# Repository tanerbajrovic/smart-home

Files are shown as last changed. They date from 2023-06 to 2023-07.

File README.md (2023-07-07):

# Smart Home

## About

An intruder alarm system realised on Raspberry Pi Pico. Our system currently supports following functionalities:

- Passcode setup
- User-friendly GUI
- Alarm activation and deactivation
  - Deactivation over MQTT protocol
- Movement detection and siren activation
- Protection against too many unlock attempts

## Components

In the project we used the following components:
- 1x Raspberry Pi Pico*
- 1x Matrix Keypad
- 1x PIR Sensor
- 1x LCD TFT Banggood Display
- 1x Buzzer

For the implementation details, documentation, or schemes please refer to the `docs` directory. 

Please also note that we actually used a modified version of Raspberry Pi Pico called PicoETF, developed at ETF Sarajevo. The differences are minute but important to state because of possible differences in schematics.

## Team Members

Below you can see all the team members who worked on this project.
- [Taner Bajrovic](mailto:tbajrovic1@etf.unsa.ba)
- [Edwin Graza](mailto:egraza1@etf.unsa.ba)
- [Ajna Mujkić](mailto:amujkic1@etf.unsa.ba)

## Notice
This project was done as part of coursework for **Embedded Systems 22/23** at the Faculty of Electrical Engineering Sarajevo.

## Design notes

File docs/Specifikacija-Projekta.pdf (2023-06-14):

### Specifikacija projekta iz

### Ugradbenih Sistema

# Smart Home

### Taner Bajrovic´, Edwin Graca, Ajna Mujkic´

## 1 Uvod

Osnovna ideja sistema pametne kuće je integracija grijanja, hladenja, rasvjete, te alarma protiv provale i požara. U osnovi cijelog sistema je jedan procesorski sistem koji kontroliše i upravlja svim ostalim kućnim sistemima. Centralni procesor dobija te informacije iz vanjskog svijeta putem raznih senzora.

U našem projektu, mi ćemo se fokusirati na implementaciju alarmnog sistema pametne kuće. U pitanju je sistem koji će omogućiti da se odredeni prostor pokrije senzorima za detekciju pokreta, aktivira/deaktivira alarm, te u odredenim situacijama aktivira sirena. Osim toga, sistem će omogućiti da se pošalje signal korisniku ukoliko se neko nalazi ispred vrata.

## 2 Implementacija

U ovom dijelu ćemo predložiti listu hardverskih komponenti, kao i predstaviti funkcionalnosti sistema.

### 2.1 Hardverske komponente

Za izradu zamišljenog sistema, potrebne su sljedeće komponente:

- 1x Raspberry Pi Pico (PicoETF)
- 1x Matrična tastatura
- 2x Magnetni senzor
- 3x PIR senzor
- 1x Fotootpornik
- 1x LCD displej (Banggood TFT)
- 1x Buzzer/Beeper (alt. LED dioda)

Povezanost izmedu pomenutih komponenti sistema i potencijalni raspored možete vidjeti na Slici 1.

1

Ugradbeni sistemi 2022./2023. | Specifikacija projekta

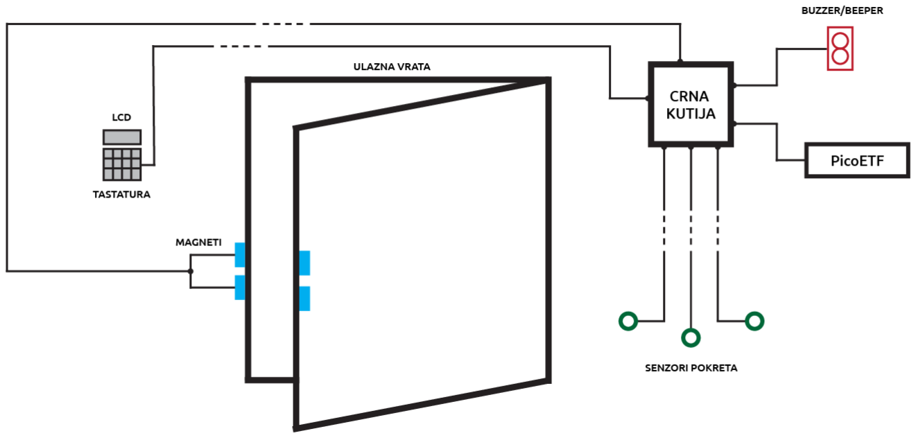
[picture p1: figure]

Slika 1: Prikaz pozicija i povezanosti komponenti

### 2.2 Funkcionalnosti sistema

Zamišljeni sistem ima sljedeće funkcionalnosti:

- Aktivacija/deaktivacija alarma. Korisnik će moći da izvrši aktivaciju i deaktivaciju alarma pomoću LCD displeja i matrične tastature. Ulaskom u odredeni režim rada i potom unosom šifre, korisnik će moći aktivirati alarm. Deaktivacija alarma će se obavljati unosom ispravne šifre nakon što je alarm već aktiviran.
- Odredeni period za unos šifre. Nakon što otvori vrata, korisnik će morati ukucati šifru u odredenom vremenskom periodu. Ukoliko to ne uradi, sistem će aktivirati zvučni signal pomoću sirene.
- Paljenje sirene u slučaju pogrešne šifre ili aktivacije senzora pokreta. U slučaju da korisnik prilikom deaktivacije alarma unese neispravnu šifru, sistem će aktivirati zvučni signal pomoću sirene/buzzer-a. Ista sirena će biti aktivirana ukoliko neki od PIR senzora detektuje neko kretanje.
- Deaktivacija sirene i alarma. Nakon što je aktivirana sirena, korisnik će moći deaktivirati alarm i sirenu unosom ispravne šifre.
- Obavještavanje o posjeti. U slučaju da se neka osoba nalazi ispred vrata, sistem će to moći detektovati i tu informaciju prenijeti korisniku.

2

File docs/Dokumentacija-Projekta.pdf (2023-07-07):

Dokumentacija Projekta iz

Ugradbenih Sistema

# Smart Home

### Taner Bajrovic´, Edwin Graca, Ajna Mujkic´

## Sadržaj

1 Uvod | 1
2 Dijagram stanja | 1
3 Kod | 1
3.1
3.2
3.3
3.4
3.5
Korištene oznake CLS | Klasa Oznaka za klasu MDL | Modul Oznaka za modul

host/tema Oznaka za temu

Stanje Oznaka za stanje

Ugradbeni sistemi 2022./2023. | Dokumentacija projekta

## 1 Uvod

Kao projekat na predmetu ‘Ugradbeni Sistemi’ implementirali smo alarm koji se može integrirati u neki Smart house sistem. Sklop omogućava da se odredeni prostor pokrije senzorima za detekciju pokreta, aktivira/deaktivira alarm te unese lozinka za njegovo isključivanje. Unos lozinke se izvršava putem displeja i tastature. Ako je detektovano kretanje u zaštićenoj zoni, vlasniku se šalje poruka na mobitel putem MQTT protokola, a on može i isključiti alarm putem aplikacije koja podržava MQTT.

## 2 Dijagram stanja

Prvobitno je alarm u stanju Deactivated . Ako se osoba pojavi u zaštićenoj zoni aktivira se alarm i sistem prelazi u stanje Activated i u njemu ostaje sve dok korisnik ima preostalih pokušaja za unos lozinke. Ukoliko se netačna lozinka unese 3 puta sistem ulazi u stanje Bricked i u njemu ostaje dok ima napajanja.

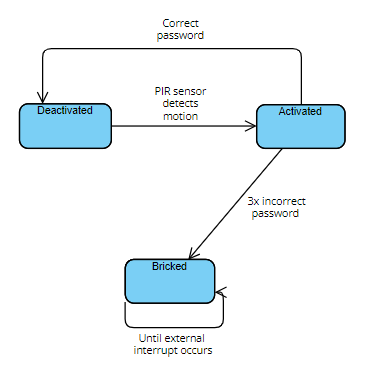
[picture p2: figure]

Slika 1. State diagram

## 3 Kod

3.1

### CLSAlarmState

Klasa

CLSAlarmState , koja se nalazi unutar modula

MDL Alarm , sadrži metode za prijelaze izmedu različitih stanja u kojima se sistem može nalaziti. U nastavku ćemo ukratko proći kroz metode ove klase te objasniti ulogu svake:

hasCode(self)-> bool

Provjerava da li je postavljena lozinka.

isLocked(self)-> bool

Provjerava da li je alarm uključen.

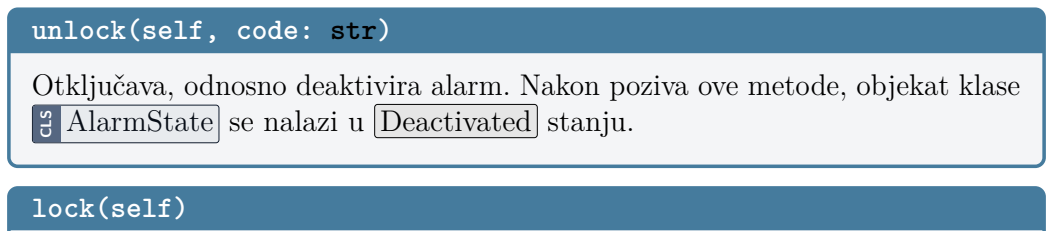
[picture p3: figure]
unlock(self, code: str); lock(self)

Otključava, odnosno deaktivira alarm. Nakon poziva ove metode, objekat klase CLS | AlarmState se nalazi u Deactivated stanju.

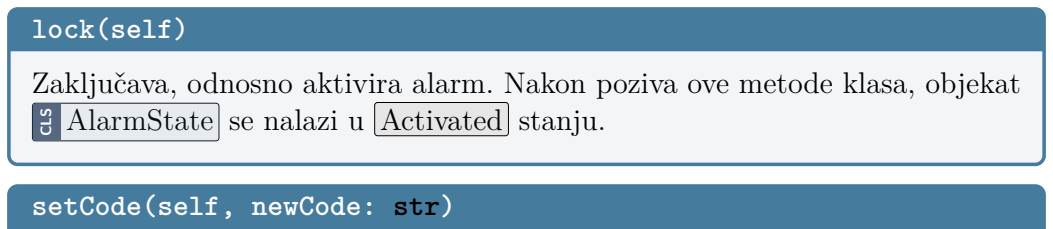
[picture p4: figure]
setCode(self, newCode: str)

Zaključava, odnosno aktivira alarm. Nakon poziva ove metode klasa, objekat CLS | AlarmState se nalazi u Activated stanju.

Postavlja novu lozinku koja je proslijedena kao argument newCode.

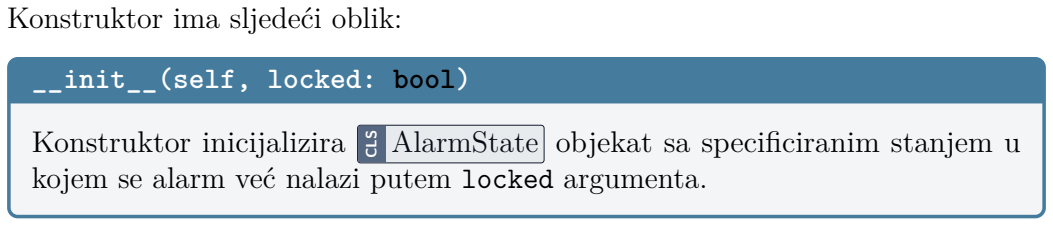
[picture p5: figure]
Konstruktor ima sljedeći oblik:; __init__(self, locked: bool); Konstruktor inicijalizira

CLSAlarmState objekat sa specificiranim stanjem u kojem se alarm već nalazi putem locked argumenta.

3.2

### MDL Keypad

Modul

MDL Keypad se koristi za očitavanje unesenog karaktera sa tastature. Njena jedina metoda je Keypad4x4Read(cols, rows), prikazana u nastavku:

Keypad4x4Read(cols, rows)-> str

Metoda čita unos sa tastature te vraća uneseni karakter koji je tipa str. Implementacijom debouncing-a smo osigurali da se uvijek vrati tačno jedan karakter za svaki pritisak na taster.

3.3

### MDL Mqtt

Modul

MDL Mqtt uspostavlja Wi-Fi konekciju, povezuje se na MQTT broker i upravlja buzzer-om na osnovu MQTT poruka. Ovaj modul omogućava semi-duplex komunikaciju koristeći sljedeće teme:

- ushome/alarmCommands Primanje kontrolnih komandi

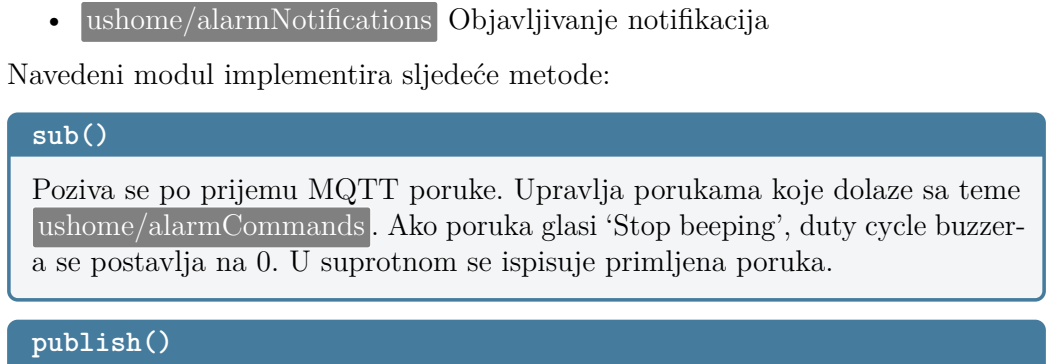
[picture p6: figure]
• ushome/alarmNotifications Objavljivanje notifikacija; Navedeni modul implementira sljedeće metode:; sub(); publish()

Poziva se po prijemu MQTT poruke. Upravlja porukama koje dolaze sa teme ushome/alarmCommands . Ako poruka glasi ‘Stop beeping’, duty cycle buzzer-a se postavlja na 0. U suprotnom se ispisuje primljena poruka.

3.4

### MDL Main

U

MDL Main modulu se odvija glavna logika programa. U ovom dijelu su definirane metode za različite izglede displeja, te za specificiranje ponašanja alarma ovisno da li se nalazi u Activated , Deactivated , ili Bricked stanju.

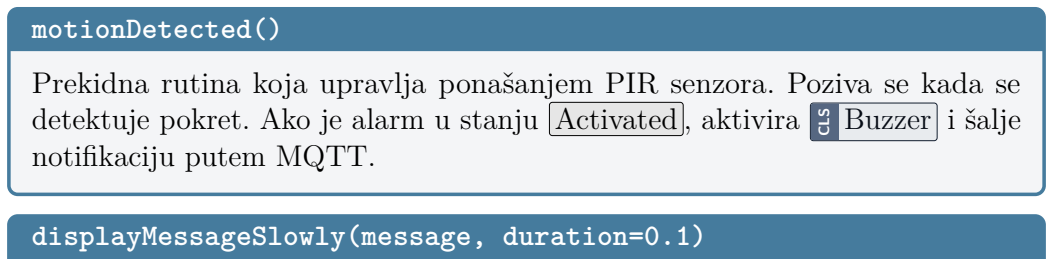
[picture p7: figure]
motionDetected(); CLSBuzzer i šalje; notifikaciju putem MQTT.; displayMessageSlowly(message, duration=0.1)

Prekidna rutina koja upravlja ponašanjem PIR senzora. Poziva se kada se detektuje pokret. Ako je alarm u stanju Activated , aktivira

Ispisuje poruku na TFT displej karakter po karakter uz definiranu pauzu izmedu karaktera.

showStartupMessage()

Ispisuje prvu poruku na ekranu koja se sastoji od pozdrava, naziva i verzije uredaja.

showWaitScreen()

Ispisuje ’loading’ ekran na displej.

showUnlockedScreen()

Upravlja logikom za slučaj kada alarm nije aktivan. Ako lozinka nije postavljena, od korisnika se zatraži postavljanje te potvrda lozinke, a u suprotnom se zatraži aktivacija alarma.

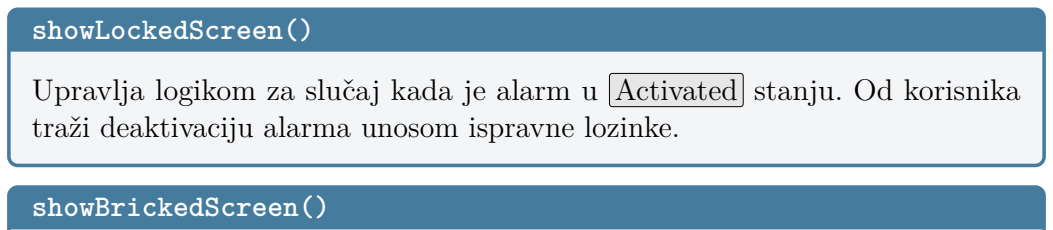
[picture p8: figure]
showLockedScreen(); showBrickedScreen()

Upravlja logikom za slučaj kada je alarm u Activated stanju. Od korisnika traži deaktivaciju alarma unosom ispravne lozinke.

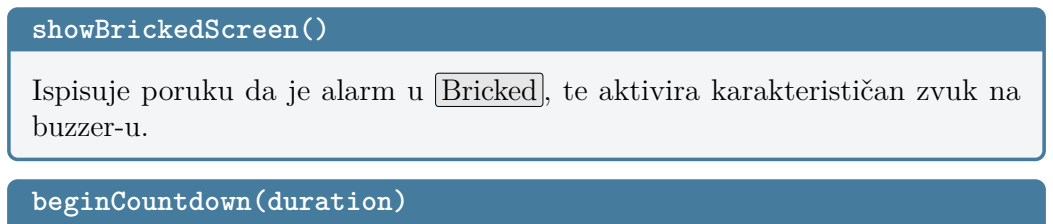
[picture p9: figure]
buzzer-u.; beginCountdown(duration)

Ispisuje poruku da je alarm u Bricked , te aktivira karakterističan zvuk na

Ispisuje poruku o čekanju i odbrojava onoliko vremena koliko je navedeno u parametru funkcije.

inputSecretCode()

Cita karaktere koje korisnik unosi na tastaturi, spaja ih u string i vraća tako ˇ formirani string.

setNewCode()

Traži od korisnika da unese i potvrdi novu lozinku. Ako su obje unesene lozinke identične, ažurira postojeću lozinku i ispisuje poruku o uspješnoj izmjeni. U suprotnom, ispisuje poruku o grešci.

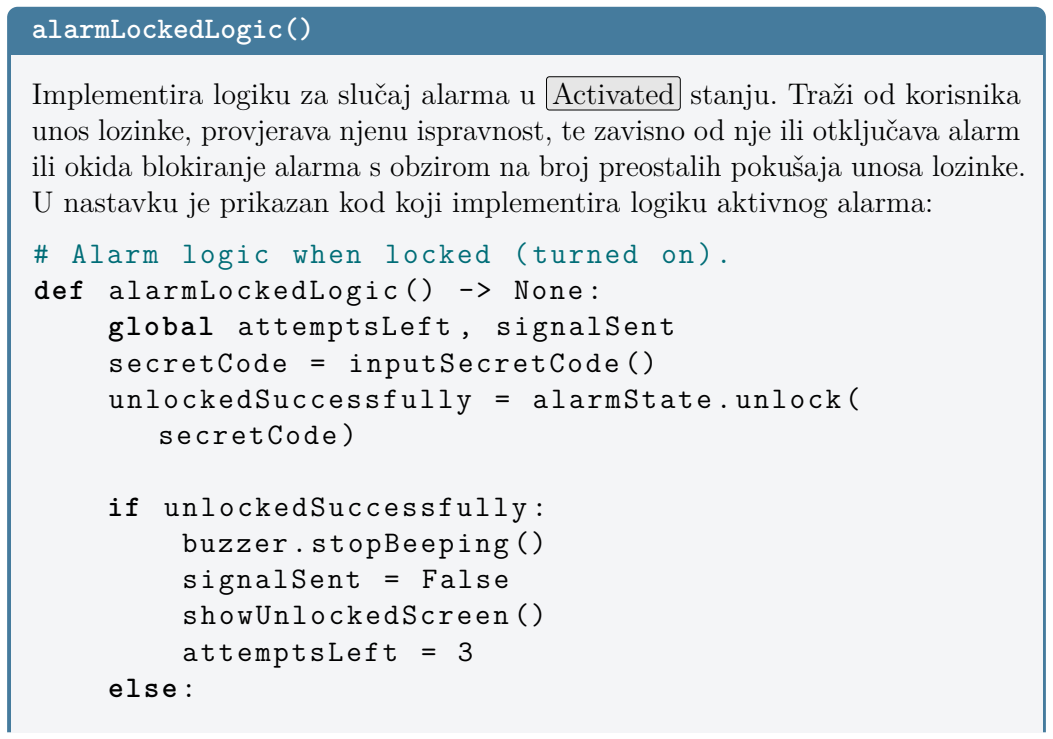
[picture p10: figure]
alarmLockedLogic(); # Alarm logic when locked ( turned on). def alarmLockedLogic () -> None :; global attemptsLeft , signalSent secretCode = inputSecretCode (); secretCode ); if unlockedSuccessfully : buzzer . stopBeeping (); signalSent = False showUnlockedScreen (); attemptsLeft = 3 else:

Implementira logiku za slučaj alarma u Activated stanju. Traži od korisnika unos lozinke, provjerava njenu ispravnost, te zavisno od nje ili otključava alarm ili okida blokiranje alarma s obzirom na broj preostalih pokušaja unosa lozinke. U nastavku je prikazan kod koji implementira logiku aktivnog alarma:

unlockedSuccessfully = alarmState . unlock (

publish (" Incorrect password entered ") attemptsLeft -= 1
if attemptsLeft == 0:
showBrickedScreen ()
display . erase ()
display . set_pos ( LEFT_MARGIN , TOP_MARGIN + 40) display . print( f" Incorrect password . You have { attemptsLeft } attempt (s) left .")

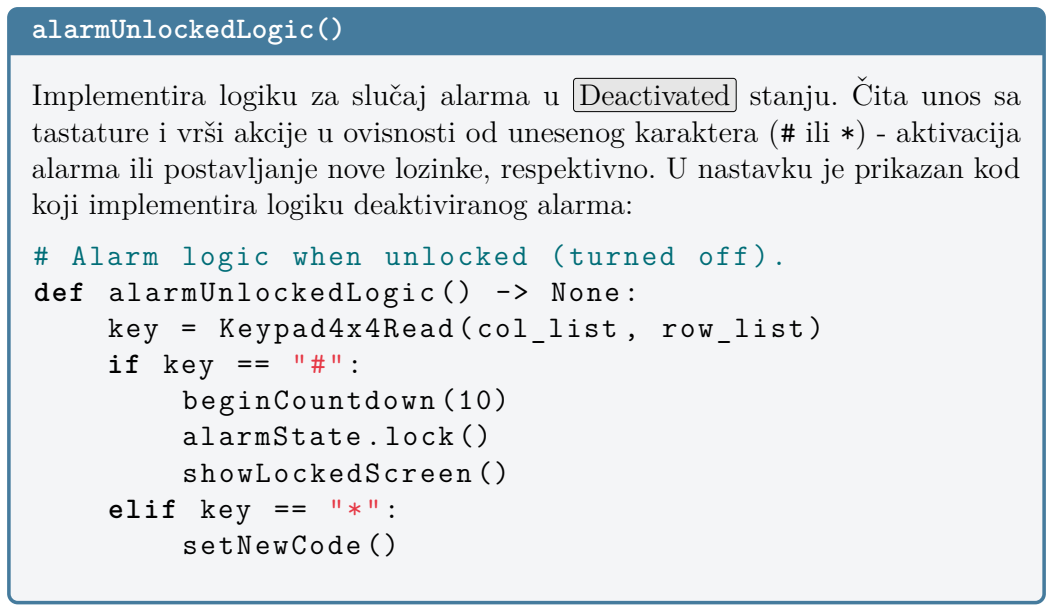
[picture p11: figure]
alarmUnlockedLogic(); koji implementira logiku deaktiviranog alarma:; def alarmUnlockedLogic () -> None :; if key == "#": beginCountdown (10) alarmState . lock () showLockedScreen (); elif key == "*": setNewCode ()

Implementira logiku za slučaj alarma u Deactivated stanju. Cita unos sa ˇ tastature i vrši akcije u ovisnosti od unesenog karaktera (# ili *) - aktivacija alarma ili postavljanje nove lozinke, respektivno. U nastavku je prikazan kod

# Alarm logic when unlocked ( turned off ).

key = Keypad4x4Read ( col_list , row_list )

3.5

### CLSBuzzer

Klasa

CLSBuzzer nudi interfejs za upravljanje buzzer komponentom koristeći širinsko-impulsnu modulaciju (PWM). Omogućava postavljanje duty cycle-a i frekvencije PWM signala u svrhu kontrolisanja zvuka koji proizvodi buzzer. Ovo je postignuto sljedećim statičkim atributima, čije vrijednosti odgovaraju duty-cycle vrijednosti:

- LOW = 0
- MID = 32000
- HIGH = 64000

Klasa implementira sljedeće metode:

setDuty(self, pin_number: int)

Postavlja duty cycle buzzer-a na vrijednost specificiranu parametrom.

setFrequency()

Postavlja frekvenciju buzzer-a na vrijednost specificiranu parametrom.

stopBeeping()

Postavlja duty cycle buzzer-a na minimalnu vrijednost (LOW).

startBeeping()

Postavlja duty cycle buzzer-a na neku srednju vrijednost (MID) definiranu konstantom iz globalnog opsega.

startScreaming()

Postavlja duty cycle buzzer-a na maksimalnu vrijednost (HIGH).

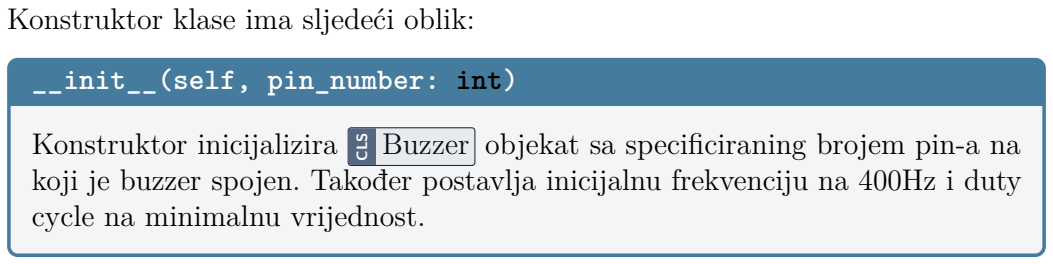
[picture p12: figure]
Konstruktor klase ima sljedeći oblik:; __init__(self, pin_number: int); Konstruktor inicijalizira; cycle na minimalnu vrijednost.

CLSBuzzer objekat sa specificiraning brojem pin-a na koji je buzzer spojen. Takoder postavlja inicijalnu frekvenciju na 400Hz i duty

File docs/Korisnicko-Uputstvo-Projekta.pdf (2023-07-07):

### Korisnicka uputstva Projekta iz ˇ

### Ugradbenih Sistema

# Smart Home

### Taner Bajrovic´, Edwin Graca, Ajna Mujkic´

## Sadržaj

1 Početni ekran | 1
2 Dodavanje nove lozinke | 2
3 Aktivacija alarma | 3
4 Deaktivacija alarma | 4
5 Blokiran alarm | 5

Ugradbeni sistemi 2022./2023. | Korisnička uputstva

## 1 Početni ekran

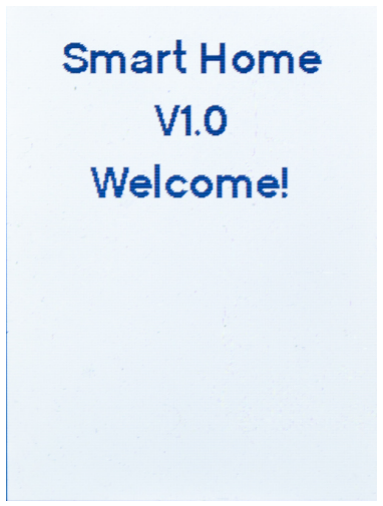
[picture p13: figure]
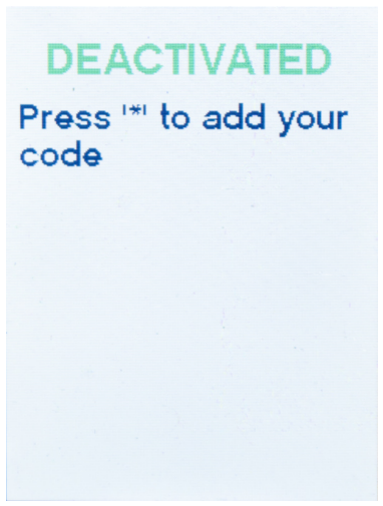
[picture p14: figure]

(a) Početni ekran | (b) Deaktivirano - dodaj novu lozinku

Slika 1. Prvo pokretanje sistema

Alarmni sistem vas prvo pozdravlja na ekranu za pokretanje (Slika 1a). Nakon što je sistem uspješno pokrenut, sistem će vam zatim zatražiti da pritisnete * (zvjezdica) kako biste prvi put postavili svoju lozinku alarma (Slika 1b).

## 2 Dodavanje nove lozinke

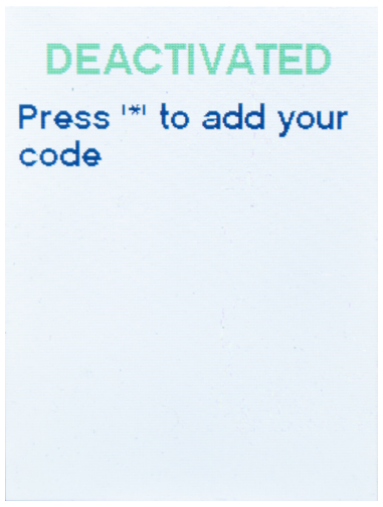
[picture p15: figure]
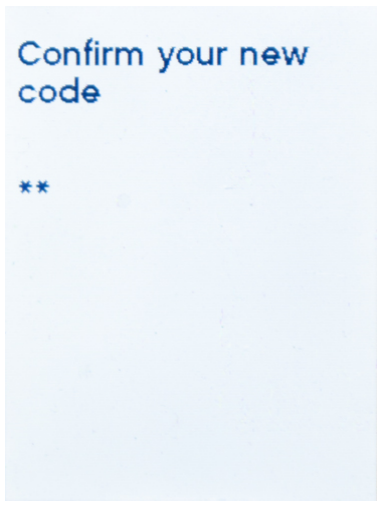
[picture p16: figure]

(a) Deaktivirano - dodaj novu lozinku | (b) Potvrda lozinke

Slika 2. Dodavanje nove lozinke

Možete postaviti lozinku od 4 cifre. gdje ćete je morati unijeti dva puta da biste je pravilno postavili (Slika 2b). Ukoliko ne unesete istu lozinku oba puta, ona neće biti promijenjena.

Ukoliko ne postavite lozinku, alarm će se moći deaktivirati bilo kojom lozinkom. Predlažemo da postavite novu lozinku odmah prilikom prvog pokretanja sistema. Lozinku je moguće promijeniti pritiskom na * svaki put kada je alarm u deaktiviranom stanju.

## 3 Aktivacija alarma

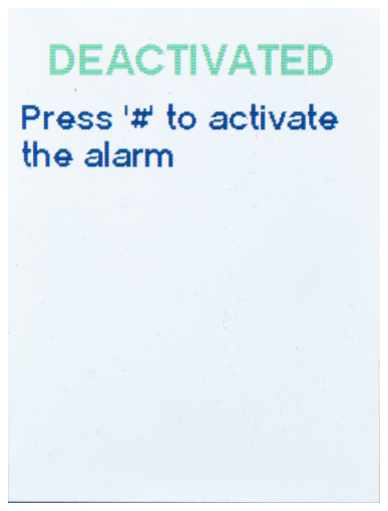
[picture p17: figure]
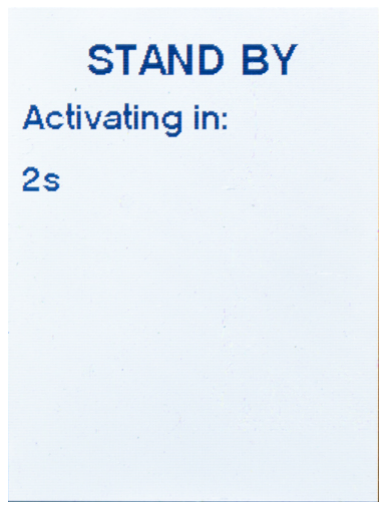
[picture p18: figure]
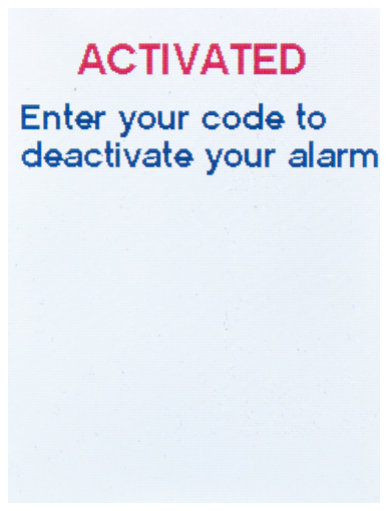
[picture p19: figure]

(a) Aktivaciju alarma | (b) Odbrojavanje do aktivacije | (c) Akvtiviran alarm

Slika 3. Koraci aktivacije alarma

Nakon postavljanja lozinke vaš alarm je spreman za rad!

Kada odlučite da želite aktivirati vaš alarmni sistem, pritisnite tipku # (Slika 3a). U trenutku kada pritisnete tipku #, pokrenut će se odbrojavanje od 10s prije nego što alarm postane aktiviran (Slika 3b). U ovom periodu nije moguće prekinuti odbrojavanje.

Nakon isteka ovog perioda, alarm će postati aktivan (Slika 3c) i svaki pokret koji detektuje senzor pokreta će uključiti sirenu.

## 4 Deaktivacija alarma

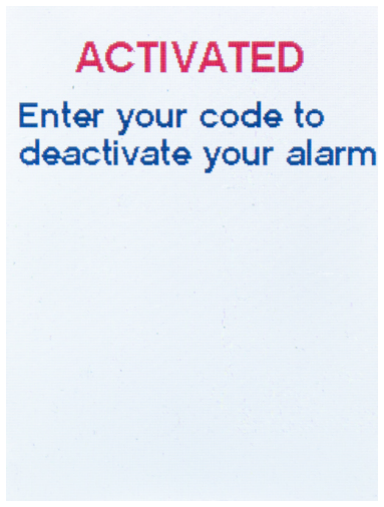
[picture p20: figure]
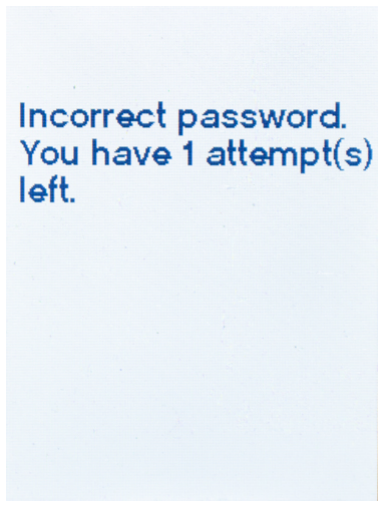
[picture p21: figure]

(a) Aktiviran alarm | (b) Unos neispravne lozinke

Slika 4. Koraci deaktivacije alarma

Kada budete spremni deaktivirati alarm, potrebno je da unesete svoju lozinku. Za unos ispravne lozinke imate samo tri pokušaja. Nakon što unesete ispravnu lozinku, sistem vratiti na zaslon DEACTIVATED kao u prethodnim slikama (Slika 3a).

Za slučaj pogrešno unesene lozinke, sistem će vam ispisati upozorenje i preostali broj pokušaja (Slika 4b).

Ukoliko tri puta unseste neispravnu lozinku, sistem će se blokirati (Pročitati više u dijelu Blokiran alarm).

## 5 Blokiran alarm

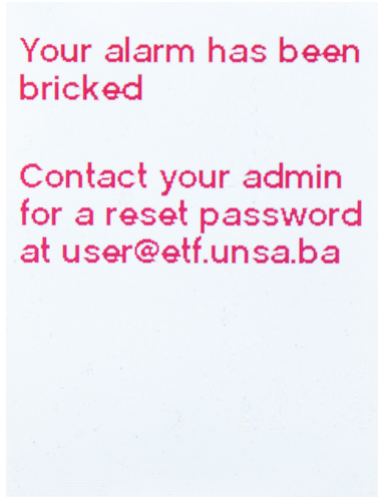
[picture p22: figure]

Slika 5. Blokiran alarm

Ukoliko prilikom deaktivacije sistema tri puta unesete neispravnu lozinku, vaš sistem će se zablokirati. Nakon toga nije više moguće izvršiti deaktivaciju bez pomoći administratora.

Vašeg administratora možete kontaktirati putem mail-a koji je ispisan na ekranu.

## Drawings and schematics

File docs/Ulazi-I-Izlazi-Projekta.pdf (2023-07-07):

# Smart Home

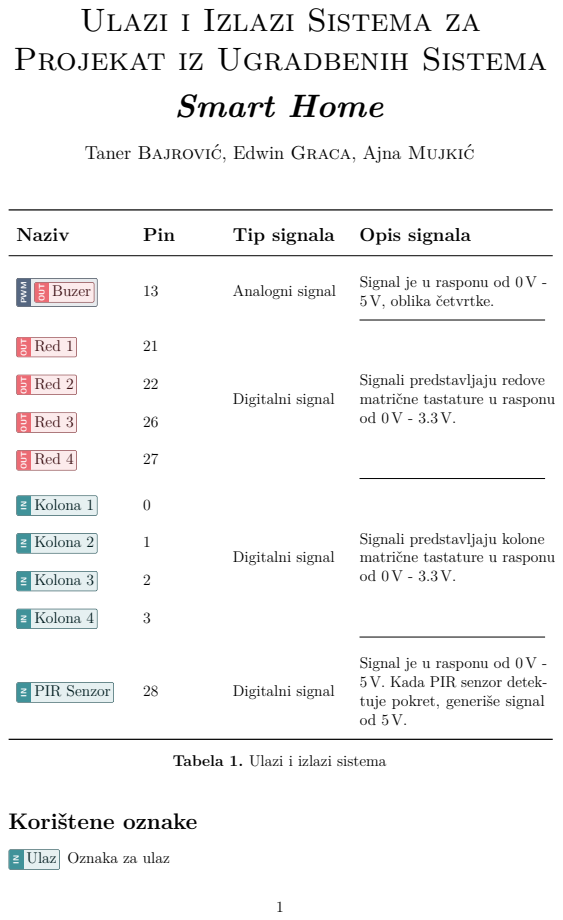
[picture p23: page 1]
Naziv; Pin; Tip signala; Opis signala PWM; OUT; Buzer; Analogni signal; Signal je u rasponu od 0 V -; 5 V, oblika ˇcetvrtke.; OUT Red 1 21; Digitalni signal; PIR Senzor; Koriˇstene oznake IN; Ulaz Oznaka za ulaz

Ulazi i Izlazi Sistema za

Projekat iz Ugradbenih Sistema

Taner Bajrovic´, Edwin Graca, Ajna Mujkic´

OUT Red 2 22 OUT Red 3 26 OUT Red 4 27 INKolona 1 0

Signali predstavljaju redove
matriˇcne tastature u rasponu

INKolona 2 1 INKolona 3 2 INKolona 4 3 IN

Signali predstavljaju kolone

Signal je u rasponu od 0 V -
5 V. Kada PIR senzor detek-
tuje pokret, generiˇse signal

Tabela 1. Ulazi i izlazi sistema

Ugradbeni sistemi 2022./2023. | Ulazi i izlazi sistema OUT

Izlaz Oznaka za izlaz

PWM
PWM Oznaka za PWM signal

2

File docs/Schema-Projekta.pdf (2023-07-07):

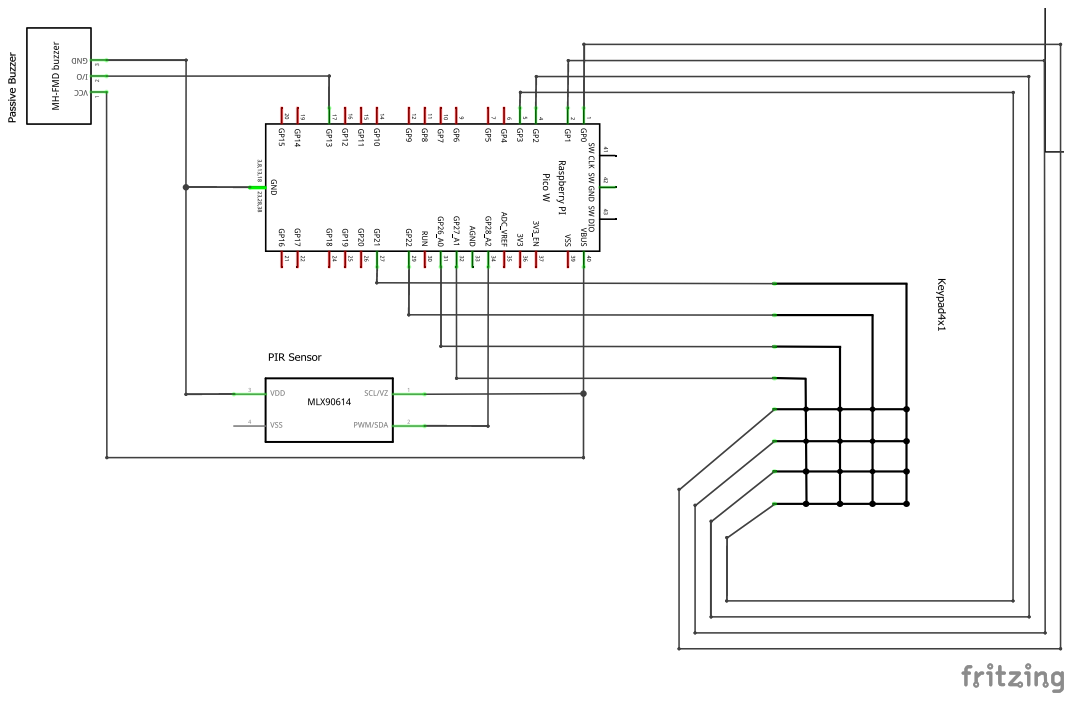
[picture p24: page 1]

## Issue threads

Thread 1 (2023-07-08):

Possible Improvements

tanerbajrovic, 2023-07-08:
# General
- [ ] **Support for multiple passcodes**. Allow multiple users to have unique passwords.
- [ ] **Backup passcode for deactivation when in `Bricked` mode**. An administrator would provide a backup passcode to user if they forget their own.

# Security
- [ ] **Use of EPROM to prevent power-outage reset**. Using EPROM will allow for passcode to be stored in non-volatile memory. In the case of device reset due to power-outage, it will return to its previous state.

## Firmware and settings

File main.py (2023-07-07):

# General Imports
from time import sleep, time
from machine import SPI
from micropython import const
from alarm import AlarmState
from buzzer import Buzzer
from colors import WHITE, BLUE, RED, GREEN
from mqtt import *

# Display-related imports
from ili934xnew import ILI9341
from keypad import *
import tt24, tt32

# Device Info
deviceName = "Smart Home"
deviceVersion = "1.0"
adminContact = "user@etf.unsa.ba"

# Inputs/Outputs
alarmState = AlarmState(locked = False)
pirSensor = Pin(28, Pin.IN)
buzzer = Buzzer(13)

# Tracks whether movement detection has been sent 
signalSent = False

# Handler method for IRQ interrupt of PIR sensor.
def motionDetected(t):
    global signalSent
    # print("-> Movement Detected")
    if alarmState.isLocked():  # Intruder alert
        # print("Currently locked")
        buzzer.startBeeping()
        if not signalSent:
            publish("Motion detected")
            signalSent = True        
    else:
        # print("Currently unlocked")
        buzzer.stopBeeping()


pirSensor.irq(motionDetected, Pin.IRQ_RISING)

# Display setup
SCR_WIDTH = const(320)
SCR_HEIGHT = const(240)
SCR_ROT = const(2)
CENTER_Y = int(SCR_WIDTH / 2)
CENTER_X = int(SCR_HEIGHT / 2)
LEFT_MARGIN = 10
TOP_MARGIN = 20

# SPI comms with display
TFT_CLK_PIN = const(18)
TFT_MOSI_PIN = const(19)
TFT_MISO_PIN = const(16)
TFT_CS_PIN = const(17)
TFT_RST_PIN = const(20)
TFT_DC_PIN = const(15)

spi = SPI(
    0,
    baudrate=62500000,
    miso=Pin(TFT_MISO_PIN),
    mosi=Pin(TFT_MOSI_PIN),
    sck=Pin(TFT_CLK_PIN))

display = ILI9341(
    spi,
    cs=Pin(TFT_CS_PIN),
    dc=Pin(TFT_DC_PIN),
    rst=Pin(TFT_RST_PIN),
    w=SCR_WIDTH,
    h=SCR_HEIGHT,
    r=SCR_ROT)

display.erase()
display.set_pos(0, 0)
display.set_font(tt32)
display.set_color(BLUE, WHITE)

fonts = ["tt24", "tt32"]
activeFont = fonts[1]

def displayMessageSlowly(message: str, duration = 0.1) -> None:
    totalLength = 0
    if activeFont == fonts[0]:
        totalLength = tt24.get_width(message)
    else:
        totalLength = tt32.get_width(message)
    startPosition = (SCR_HEIGHT - totalLength) // 2
    display.set_pos(startPosition, display._y)
    for character in message:
        display.write(character)
        sleep(duration)


# ? Refactor this.
def showStartupMessage() -> None:
    display.erase()
    display.set_pos(LEFT_MARGIN, TOP_MARGIN)
    displayMessageSlowly(deviceName)
    display.set_pos(LEFT_MARGIN, TOP_MARGIN + 40)
    displayMessageSlowly(f"V{deviceVersion}")
    display.set_pos(LEFT_MARGIN, TOP_MARGIN + 80)
    displayMessageSlowly("Welcome!")
    sleep(1)


# Waiting screen view
def showWaitScreen() -> None:
    # Setup
    display.erase()
    display.set_font(tt32)
    display.set_pos(LEFT_MARGIN, TOP_MARGIN + 40)
    displayMessageSlowly("Loading...")
    sleep(1)


# Unlocked screen view
def showUnlockedScreen() -> None:
    display.erase()
    display.set_pos(LEFT_MARGIN, TOP_MARGIN)
    display.set_font(tt32)
    display.set_color(GREEN, WHITE)
    displayMessageSlowly("DEACTIVATED")
    display.set_color(BLUE, WHITE)
    display.set_pos(LEFT_MARGIN, TOP_MARGIN + 40)
    display.set_font(tt24)
    if not alarmState.hasCode():
        display.print("Press '*' to add your code")
    else:
        display.print("Press '#' to activate the alarm")


# Locked screen view
def showLockedScreen() -> None:
    display.erase()
    display.set_pos(LEFT_MARGIN, TOP_MARGIN)
    display.set_font(tt32)
    display.set_color(RED, WHITE)
    displayMessageSlowly("ACTIVATED")
    display.set_color(BLUE, WHITE)
    display.set_font(tt24)
    display.set_pos(LEFT_MARGIN, TOP_MARGIN + 40)
    display.print("Enter your code to  deactivate your alarm")


# Bricked screen view
def showBrickedScreen() -> None:
    display.erase()
    display.set_pos(LEFT_MARGIN, TOP_MARGIN)
    display.set_font(tt24)
    display.set_color(RED, WHITE)
    display.print("Your alarm has been bricked")
    display.set_pos(LEFT_MARGIN, TOP_MARGIN + 80)
    display.print(f"Contact your admin for a reset password at {adminContact}")
    while True:
        buzzer.startScreaming()
        sleep(0.5)
        buzzer.startBeeping()
        sleep(0.5)


# Remaining code attempts
attemptsLeft = 3

def beginCountdown(duration: int) -> None:
    display.erase()
    display.set_pos(LEFT_MARGIN, TOP_MARGIN)
    display.set_font(tt32)
    displayMessageSlowly("STAND BY")
    display.set_font(tt24)
    display.set_pos(LEFT_MARGIN, TOP_MARGIN + 40)
    display.print("Activating in:")
    remainingTime = duration
    while remainingTime:
        display.set_pos(LEFT_MARGIN, TOP_MARGIN + 80)
        display.print(f"{remainingTime}s")
        remainingTime -= 1
        sleep(1)


# Logic for code verification and alarm deactivation
def inputSecretCode() -> str:
    global pin_digits, attemptsLeft
    # display.erase()
    display.set_font(tt32)
    display.set_pos(LEFT_MARGIN, display._y + 40)
    pin_digits = []
    while len(pin_digits) < 4:
        mqtt_conn.check_msg()
        key = Keypad4x4Read(col_list, row_list)
        if key != None:
            if key.isdigit():
                display.write("*")
                pin_digits.append(int(key))
    stringCode = ""
    for digit in pin_digits:
        stringCode = stringCode + str(digit)
    display.set_font(tt24)
    return stringCode             
    

# Logic for adding a new code
def setNewCode() -> None:
    display.erase()
    display.set_pos(LEFT_MARGIN, TOP_MARGIN)
    display.print("Enter your new code")
    newCode = inputSecretCode()
    
    display.erase()
    display.set_pos(LEFT_MARGIN, TOP_MARGIN)
    display.print("Confirm your new code")
    confirmCode = inputSecretCode()
    
    if newCode == confirmCode:
        alarmState.setCode(newCode)
        display.erase()
        display.set_pos(LEFT_MARGIN, TOP_MARGIN)
        display.print("Code changed successfully!")
        sleep(1.25)
        showUnlockedScreen()
    else:
        display.erase()
        display.set_pos(LEFT_MARGIN, TOP_MARGIN)
        display.print("Codes DO NOT match!")
        display.set_pos(LEFT_MARGIN, TOP_MARGIN + 80)
        displayMessageSlowly("Alarm not active")
        sleep(1)
        showUnlockedScreen()


# Alarm logic when locked (turned on).
def alarmLockedLogic() -> None:
    global attemptsLeft, signalSent
    print("--- Locked Logic ---")
    secretCode = inputSecretCode()
    unlockedSuccessfully = alarmState.unlock(secretCode)
    
    if unlockedSuccessfully:
        buzzer.stopBeeping()
        signalSent = False
        showUnlockedScreen()
        attemptsLeft = 3
    else:
        publish("Incorrect password entered")
        attemptsLeft -= 1
        if attemptsLeft == 0:
            showBrickedScreen()
        display.erase()
        display.set_pos(LEFT_MARGIN, TOP_MARGIN + 40)
        display.print(f"Incorrect password. You have {attemptsLeft} attempt(s) left.")


# Alarm logic when unlocked (turned off).
def alarmUnlockedLogic() -> None:
    # print("--- Unlocked Logic ---")
    key = Keypad4x4Read(col_list, row_list)
    if key == "#":
        beginCountdown(10)
        alarmState.lock()
        showLockedScreen()
    elif key == "*":
        setNewCode()
        

showStartupMessage()
showWaitScreen()
showUnlockedScreen()


while True:
    if alarmState.isLocked():
        alarmLockedLogic()
    else:
        alarmUnlockedLogic()
    sleep(0.05)
    mqtt_conn.check_msg()

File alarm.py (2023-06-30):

class AlarmState:
    
    # Constructor
    def __init__(self, locked: bool):
        self.code = None
        self.resetCode = "9999"
        self.locked = locked
    
    # Is the code set?
    def hasCode(self) -> bool:
        return self.code is not None
    
    # Is the alarm on?
    def isLocked(self) -> bool:
        return self.locked
    
    # Unlock
    def unlock(self, code: str) -> bool:
        if not self.hasCode() or self.code == code:
            self.locked = False
            return not self.locked
        
    # Lock
    def lock(self) -> None:
        self.locked = True
        
    # Set code
    def setCode(self, new_code: str) -> None:
        self.code = new_code
        
      

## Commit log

2023-06-26 Fix incorrect boolean in Unlock method
    [alarm.py]
2023-07-07 Add schema, I/O specification, anf Fritzing files
    [smart-home.fzz]
